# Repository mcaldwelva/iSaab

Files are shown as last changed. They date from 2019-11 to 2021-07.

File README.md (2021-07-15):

# iSaab
This module replaces the factory CD changer on the Saab 9-3 OG and 9-5 OG. All controls behave as the original, with the following exceptions:
* RDM does not change tracks when switching to shuffle mode

* In shuffle mode, the NXT and preset buttons are used to change the display text. NXT will rotate through the tags. Each preset button will select: 1) Track Title, 2) Album Title, 3) Album Artist, 4) Track Artist, 5) Genere, or 6) Year, respectively. Pressing the same preset again will return the display to normal.

* The 9-5 intro scan controls have been repurposed for pause and resume

## Parts

This is based on the [BlueSaab 3.5mm module](http://bluesaab.blogspot.com/2014/03/how-to-build-your-own-35mm-version-of.html) with some modifications to incorporate a sound card and reduce power consumption. The following or similar parts are required:

* [iSaab board](https://oshpark.com/shared_projects/o4QRu2nz)

* [ICs, caps, resistors, etc.](https://www.mouser.com/ProjectManager/ProjectDetail.aspx?AccessID=5A5DA965B5)

* [TE 827229-1 connector](https://www.connectorpeople.com/Connector/TYCO-AMP-TE_CONNECTIVITY/8/827229-1)

* [VS1053 breakout board](https://www.amazon.com/VS1053B-Arduino-Breakout-Real-time-Recording/dp/B07KNV2YTM)

* FTDI cable

* 9-5 only: CD Changer Connector Harness (400129243)

## Build

The BOM components are labeled to match the board. Cut the ribbon cable and strip the even wires (only the bottom row is used) so that they can be solderd in place with the MCU from the underside of the board.

| VS1053 Pin | AVR Pin | Ribbon Pin |
| ---:|:--- | --- |
| 5V | 20 | 1 |
| GND | 22 | 2 |
| CARDCS | 6 (D4)  | 3 |
| MISO | 18 | 4 |
| MOSI | 17 | 5 |
| SCK | 19 | 6 |
| XCS | 13 (D7) | 7 |
| XRESET | 15 (D9) | 8 |
| XDCS | 12 (D6) | 9 |
| DREQ | 5  (D3) | 10 |

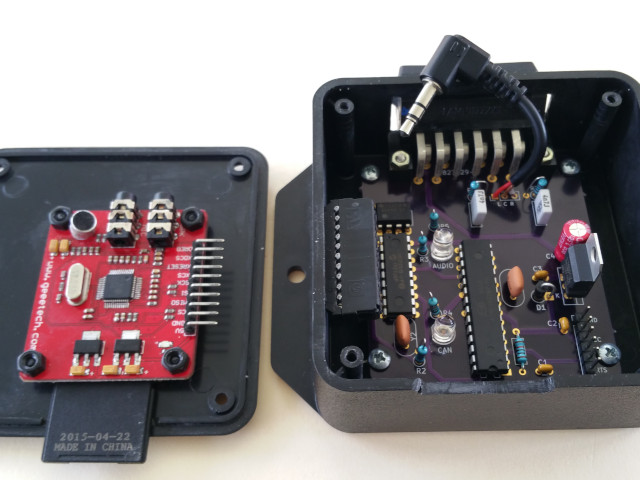
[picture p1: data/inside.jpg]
inside


## Software

* Use Arduino 1.8.12 (or higher)

* Apply the [SD library patch](https://raw.githubusercontent.com/mcaldwelva/iSaab/master/data/SD.diff) to fix issues with closing files, allow extended ASCII characters in file names, and exclude hidden/system files from directory listings:

> C:\Program Files (x86)\Arduino\libraries> patch -p1 < %HOMEPATH%\Documents\Arduino\iSaab\data\SD.diff

* Upload the iSaab code to the module using an FTDI cable

## Usage
* Format an SD card with FAT32. Third-party tools are needed to format SD cards larger than 32GB (e.g.
http://www.ridgecrop.demon.co.uk/index.htm?fat32format.htm)

* Place FLAC, Ogg Vorbis, MP3, AAC, or WMA music files into sub-directories, up-to three levels deep

* Files are played in filesystem order, which may not be as they appear in your OS. Third-party tools can be used to sort the filesystem to play in the desired order (e.g. http://www.anerty.net/software/file/DriveSort.php)

* Place [patch053.bin](https://raw.githubusercontent.com/mcaldwelva/iSaab/master/data/patch053.bin) in the root folder to enable FLAC playback.

* Create presets.txt in the root, containing up to 6 comma separated numbers. Each number represents the play-order of the file on the file system.

* Connect the module to the CD changer port in the trunk:
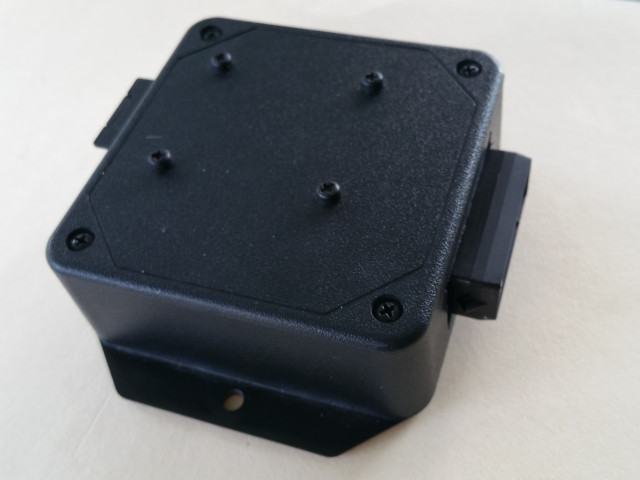
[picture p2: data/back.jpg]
back


## Troubleshooting
* The disc and track numbers are changing on the display but nothing is playing. This is expected behavior when seeking tracks. You may see this when the CD changer turns on, when selecting a preset, or between tracks in shuffle mode.

* If play doesn't start when the CD changer is selected, ensure the SD card is fully inserted. If the module is still unrespsonive, it may be necessary to disconnect and reconnect it for a hard boot.

* Only connect or disconnnect the module while the car is off and key removed from the ingition.

* When the module is shutdown, only the LED on the daughter card will remain lit to indicate power. The module draws ~13mA in this state.

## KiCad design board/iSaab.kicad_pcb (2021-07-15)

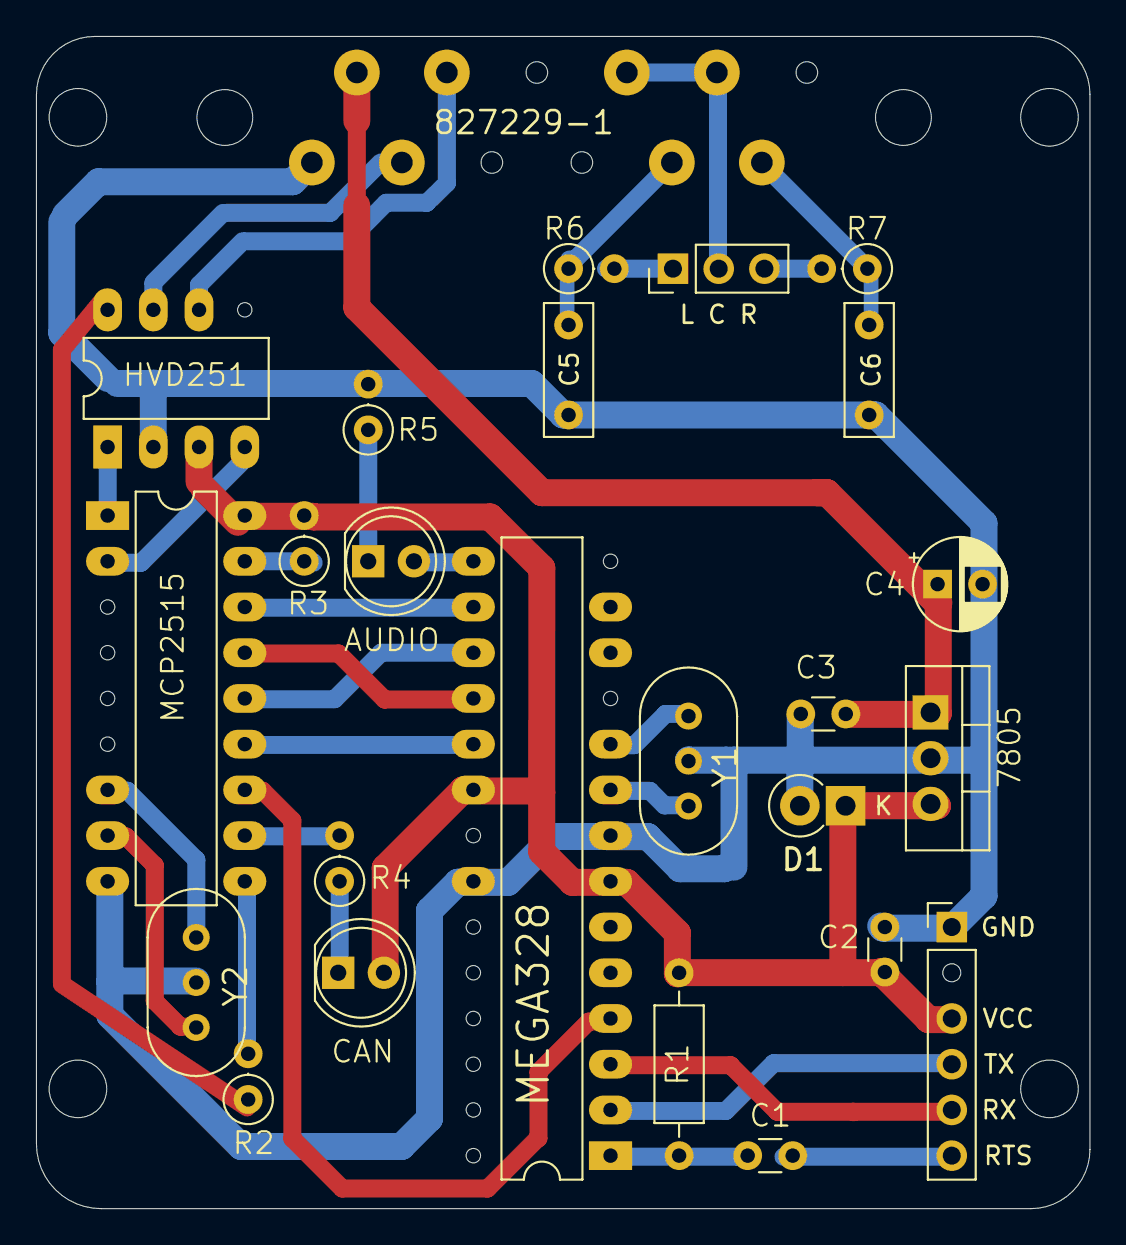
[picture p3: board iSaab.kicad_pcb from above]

Board: 2 copper layers, 58.5 x 65.1 mm, 29 parts (0 on the bottom side), 32 nets.

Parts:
@HOLE0, @HOLE1, @HOLE2, @HOLE3: (no value)
AUDIO: 5V; LED_D5.0mm
Audio In: L C R; PinHeader_1x03_P2.54mm_Vertical
C1, C2: 0.1uF; C_Disc_D3.0mm_W1.6mm_P2.50mm
C3: 470nF; C_Disc_D3.0mm_W1.6mm_P2.50mm
C4: 1uF; CP_Radial_D5.0mm_P2.50mm
C5, C6: 4.7nF; C_Rect_L7.2mm_W2.5mm_P5.00mm_FKS2_FKP2_MKS2_MKP2
CAN: 5V; LED_D5.0mm
D1: 1N4007-01; D_DO-41_SOD81_P2.54mm_Vertical_KathodeUp
IC1: MCP2515; DIP-18_W7.62mm_LongPads
IC2: HVD251; DIP-8_W7.62mm_LongPads
IC3: MEGA328; DIP-28_W7.62mm_LongPads
IC4: 7805; TO-220-3_Vertical
JP1: FTDI; PinHeader_1x06_P2.54mm_Vertical
R1: 10K; R_Axial_DIN0207_L6.3mm_D2.5mm_P10.16mm_Horizontal
R2, R3: 10K; R_Axial_DIN0207_L6.3mm_D2.5mm_P2.54mm_Vertical
R4, R5, R6, R7: 1K; R_Axial_DIN0207_L6.3mm_D2.5mm_P2.54mm_Vertical
U$5: 827229-1
Y1, Y2: 16MHz; Resonator-3Pin_W10.0mm_H5.0mm

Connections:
+5V: C2.1, CAN.2, D1.1, IC1.18, IC2.3, IC3.7, IC3.20, IC4.3, JP1.3, R1.1, R3.2
+12: C3.1, C4.1, IC4.1, U$5.6
CANH: IC2.7, U$5.11
CANL: IC2.6, U$5.5
CS: IC1.16, IC3.16
GBUF: Audio In.2, U$5.2, U$5.3
GND: C2.2, C3.2, C4.2, C5.1, C6.1, D1.2, IC1.9, IC2.2, IC3.8, IC3.22, IC4.2, JP1.1, R5.2, U$5.12, Y1.2, Y2.2
INT: IC1.12, IC3.4
LOUT: C5.2, R6.1, U$5.8
MISO: IC1.15, IC3.18
MOSI: IC1.14, IC3.17
unnamed: CAN.1, R4.1
unnamed: AUDIO.1, R5.1
unnamed: Audio In.1, R6.2
unnamed: Audio In.3, R7.2
unnamed: IC1.17, R3.1
OSC1: IC1.8, Y2.3
OSC2: IC1.7, Y2.1
RESET: C1.1, IC3.1, R1.2
ROUT: C6.2, R7.1, U$5.7
RTS: C1.2, JP1.6
RX: IC3.3, JP1.5
RX0BF: IC1.11, R4.2
RX1BF: IC1.10, R2.2
RXCAN: IC1.2, IC2.4
SCK: IC1.13, IC3.19
STDBY: IC2.8, R2.1
TOSC1: IC3.9, Y1.1
TOSC2: IC3.10, Y1.3
TX: IC3.2, JP1.4
TXCAN: IC1.1, IC2.1
XRESET: AUDIO.2, IC3.15

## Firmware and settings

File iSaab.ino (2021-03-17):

/*
 * iSaab -- A CD Changer replacement for Saab 9-3 OG and 9-5 OG
 *
 */

#include <SPI.h>
#include <avr/power.h>
#include <avr/sleep.h>
#include "CAN.h"
#include "CDC.h"
#include "iSaab.h"

uint8_t tag = AudioFile::NUM_TAGS;
bool newText;

// one-time setup
void setup() {
  // setup sound card
  CDC.setup();

#ifndef SERIALMODE
  // open I-Bus @ 47.619Kbps
  CAN.begin(47, high_filters, low_filters);

  // use IRQ for incoming messages
  SPI.usingInterrupt(MCP2515_INT);
  attachInterrupt(MCP2515_INT, processMessage, LOW);

  // reduce power
  set_sleep_mode(SLEEP_MODE_PWR_DOWN);
  power_usart0_disable();
  power_timer1_disable();
#else
  // open serial
  Serial.begin(115200);

  // use timer to read serial
  SPI.usingInterrupt(255);
  TCCR1A = 0;
  TCCR1B = _BV(WGM12) | _BV(CS12);
  OCR1A  = F_CPU / 256 / 2 - 1;
  TIMSK1 |= _BV(OCIE1A);

  // reduce power
  set_sleep_mode(SLEEP_MODE_IDLE);
#endif

  power_timer2_disable();
  power_adc_disable();
  power_twi_disable();
}


// main loop
void loop() {
  sleep_mode();
  CDC.loop();
}


// interrupt handler for incoming message
void processMessage() {
  static uint8_t gap = 0;

  // starting to receive CDC messages, wake up
  if (gap == 0) {
    CAN.setMode(CANClass::Normal);
  }

  // act on message
  CANClass::msg msg;
  if (receiveMessage(msg)) {
    switch (msg.id) {
      case RX_CDC_CONTROL:
        controlRequest(msg);
        gap = 15;
        break;

      case RX_CDC_POWER:
        powerRequest(msg);
        gap = 15;
        break;

      case RX_SID_REQUEST:
        displayRequest(msg); // comment out for vehicles equipped with Park Assist
        gap--;
        break;
    }
  }

  // no more CDC messages, go to sleep
  if (gap == 0) {
    CAN.setMode(CANClass::ListenOnly);
  }
}


void powerRequest(CANClass::msg &msg) {
  uint8_t action = msg.data[3] & 0x0f;

  // reply id
  msg.id = TX_CDC_POWER;

  // handle power request
  switch (action) {
    case 0x2: // active
      msg.data[3] = 0x16;
      break;
    case 0x3: // power on
      msg.data[3] = 0x03;
      CDC.on();
      break;
    case 0x8: // power off
      msg.data[3] = 0x19;
      CDC.off();
      break;
  }
  msg.data[0] = 0x32;
  msg.data[1] = 0x00;
  msg.data[2] = 0x00;
  msg.data[4] = 0x01;
  msg.data[5] = 0x02;
  msg.data[6] = 0x00;
  msg.data[7] = 0x00;
  sendMessage(msg);

  // send rest of sequence
  switch (action) {
    case 0x2: // active
      msg.data[3] = 0x36;
      break;
    case 0x3: // power on
      msg.data[3] = 0x22;
      break;
    case 0x8: // power off
      msg.data[3] = 0x38;
      break;
  }
  msg.data[4] = 0x00;
  msg.data[5] = 0x00;
  while (msg.data[0] < 0x62) {
    msg.data[0] += 0x10;
    sendMessage(msg);
  }
}


void controlRequest(CANClass::msg &msg) {
  static int8_t repeatCount;

  // reply id
  msg.id = TX_CDC_CONTROL;

  // ready, reply
  msg.data[0] = 0x60;

  // map CDC commands to methods
  repeatCount++;
  switch (msg.data[1]) {
    case 0x00: // no command
      msg.data[0] = 0x20;
      repeatCount = 0;
      CDC.normal();
      break;
    case 0x35: // TRACK >>
      CDC.skipTrack(repeatCount);
      break;
    case 0x36: // TRACK <<
      CDC.skipTrack(1 - repeatCount);
      break;
    case 0x45: // PLAY >>
      CDC.skipTime(repeatCount);
      break;
    case 0x46: // PLAY <<
      CDC.skipTime(-repeatCount);
      break;
    case 0x59: // NXT
      if (repeatCount == 1) {
        if (CDC.isShuffled()) {
          // rotate display tag
          tag = (tag + 1) % (AudioFile::NUM_TAGS + 1);
          newText = true;
        } else {
          CDC.nextDisc();
        }
      }
      break;
    case 0x68: // 1 - 6
      if (repeatCount == 1) {
        uint8_t preset = msg.data[2] - 1;
        if (CDC.isShuffled()) {
          // hide/show display tag
          tag = (preset == tag) ? AudioFile::NUM_TAGS : preset;
          newText = true;
        } else {
          CDC.preset(preset);
        }
      }
      break;
    case 0x76: // RDM toggle
      if (repeatCount == 1) {
        msg.data[0] |= 0x80;
        CDC.shuffle();
      }
      break;
    case 0xb0: // MUTE on
    case 0x14: // deselect CDC
    case 0x84: // SCAN disc
      CDC.pause();
      break;
    case 0xb1: // MUTE off
    case 0x24: // select CDC
    case 0x88: // SCAN magazine
      CDC.resume();
      break;
  }

  msg.data[1] = 0x00;

  // magazine
  msg.data[2] = 0b00111111;

  // play status, disc
  msg.data[3] = CDC.getState() & 0xf0;
  msg.data[3] |= CDC.getDisc() % 6 + 1;

  // track
  uint8_t track = CDC.getTrack() + 1;
  msg.data[4] = (track / 10) % 10;
  msg.data[4] <<= 4;
  msg.data[4] |= track % 10;

  // minutes
  uint16_t time = CDC.getTime();
  uint8_t min = time / 60;
  msg.data[5] = (min / 10) % 10;
  msg.data[5] <<= 4;
  msg.data[5] |= min % 10;

  // seconds
  uint8_t sec = time % 60;
  msg.data[6] = sec / 10;
  msg.data[6] <<= 4;
  msg.data[6] |= sec % 10;

  // married, RDM
  msg.data[7] = 0xd0;
  if (CDC.isShuffled()) msg.data[7] |= 0x20;

  // flag disc, track, or time change
  static uint8_t last[4] = {0x02, 0x01, 0x00, 0x00};
  if (memcmp(last, (msg.data + 3), sizeof(last))) {
    msg.data[0] |= 0x80;
    if (time == 0) newText = true;
    memcpy(last, (msg.data + 3), sizeof(last));
  }

  sendMessage(msg);
}


void displayRequest(CANClass::msg &msg) {
  // check row
  if (msg.data[0] == 0x00) {
    // check if display is wanted
    const String text = CDC.getText(tag);
    if (CDC.getState() == VS1053::Playing && text.length() > 0) {
      // check owner
      switch (msg.data[1]) {
        case 0x12: // iSaab
          // send text
          msg.id = TX_SID_TEXT;
          msg.data[1] = 0x96;

          for (int8_t id = 5, i = 0; id >= 0; id--) {
            // sequence id, start of sequence flag
            msg.data[0] = id;
            if (id == 5) msg.data[0] |= 0x40;

            // row id, new text flag
            msg.data[2] = (id < 3) ? 2 : 1;
            if (newText) msg.data[2] |= 0x80;

            // copy text
            switch (id) {
              default:
                msg.data[3] = text[i++];
                msg.data[4] = text[i++];
                msg.data[5] = text[i++];
                msg.data[6] = text[i++];
                msg.data[7] = text[i++];
                break;
              case 3:
                msg.data[3] = text[i++];
                msg.data[4] = text[i++];
                if (text[i] == ' ') i++;
                msg.data[5] = 0x00;
                msg.data[6] = 0x00;
                msg.data[7] = 0x00;
                break;
              case 0:
                msg.data[3] = text[i++];
                msg.data[4] = tag + 1;
                msg.data[5] = 0x00;
                msg.data[6] = 0x00;
                msg.data[7] = 0x00;
                break;
            }
            sendMessage(msg);
          }

          newText = false;
          msg.data[2] = 0x05; // keep
          break;
        case 0xff: // available
          newText = true;
          msg.data[2] = 0x03; // request
          break;
        default: // taken
          msg.data[2] = 0xff; // decline
          break;
      }
    } else {
      msg.data[2] = 0xff; // decline
    }

    // display request
    msg.id = TX_SID_REQUEST;
    msg.data[0] = 0x1f; // device
    msg.data[1] = 0x00; // row
    msg.data[3] = 0x12; // iSaab
    msg.data[4] = 0x00;
    msg.data[5] = 0x00;
    msg.data[6] = 0x00;
    msg.data[7] = 0x00;
    sendMessage(msg);
  }
}


void sendMessage(const CANClass::msg &msg) {
#ifndef SERIALMODE
  while (!CAN.send(msg));
#else
  Serial.print(msg.id, HEX);
  Serial.print(' ');

  for (uint8_t i = 0; i < 8; i++) {
    Serial.print(msg.data[i], HEX);
    Serial.print(' ');
  }

  Serial.println();
#endif
}


bool receiveMessage(CANClass::msg &msg) {
#ifndef SERIALMODE
  return CAN.receive(msg);
#else
  msg.id = RX_CDC_CONTROL;

  if (Serial.available()) {
    char c = Serial.read();

    switch (c) {
      case 'b':
        msg.id = RX_CDC_POWER;
        msg.data[3] = 0x03;
        break;
      case 'e':
        msg.id = RX_CDC_POWER;
        msg.data[3] = 0x08;
        break;
      case 't':
        msg.id = RX_SID_REQUEST;
        msg.data[0] = 0x00;
        msg.data[1] = 0x12;
        break;
      case 'p':
        msg.data[1] = 0xb0;
        break;
      case 'r':
        msg.data[1] = 0xb1;
        break;
      case '*':
        msg.data[1] = 0x76;
        break;
      case '>':
        msg.data[1] = 0x35;
        break;
      case '<':
        msg.data[1] = 0x36;
        break;
      case 'n':
        msg.data[1] = 0x59;
        break;
      case '-':
        msg.data[1] = 0x46;
        break;
      case '+':
        msg.data[1] = 0x45;
        break;
      case '1': case '2': case '3': case '4': case '5': case '6':
        msg.data[1] = 0x68;
        msg.data[2] = c - '0';
        break;
    }
  } else {
    msg.data[1] = 0x00;
  }

  return true;
#endif
}


#ifdef SERIALMODE
ISR(TIMER1_COMPA_vect) { processMessage(); }
#endif

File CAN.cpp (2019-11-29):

/*
 *  CAN implements CAN 2.0A (standard) interface for MCP2515 and related controllers
 *      based on work by Fabian Greif and Igor Real
 *   - Uses SPI transactions to allow bus sharing
 *   - Optionally use RX0BF or RX1BF to manage transceiver or mode indicator
 *
 */

#include <SPI.h>
#include <utility/Sd2PinMap.h>
#include "CAN.h"

#define MCP2515_SPI_SETTING SPISettings(10000000, MSBFIRST, SPI_MODE0)

CANClass CAN;

// setup pins, set CAN bus speed, optionally set filters, begin accepting messages
void CANClass::begin(uint16_t speed, const uint16_t high[] PROGMEM, const uint16_t low[] PROGMEM) {
  pinMode(MCP2515_CS, OUTPUT);
  digitalWrite(MCP2515_CS, HIGH);

  pinMode(MCP2515_IRQ, INPUT);

  SPI.begin();

  // reset MCP2515 to clear registers and put it into configuration mode
  SPI.beginTransaction(MCP2515_SPI_SETTING);
  fastDigitalWrite(MCP2515_CS, LOW);

  spiwrite(SPI_RESET);

  fastDigitalWrite(MCP2515_CS, HIGH);
  SPI.endTransaction();

  // wait for reset to complete
  delayMicroseconds(10);

  // configure bus speed
  uint8_t cnf1, cnf2, cnf3;
  switch (speed) {
    case 47:
      // http://www.microchip.com/forums/m/tm.aspx?m=236967&p=2
      cnf1 = 0xc7; cnf2 = 0xbe; cnf3 = 0x04;
      break;
    case 500:
      cnf1 = 0x01; cnf2 = 0x90; cnf3 = 0x02;
      break;
    case 250:
      cnf1 = 0x01; cnf2 = 0xB8; cnf3 = 0x05;
      break;
    case 125:
      cnf1 = 0x07; cnf2 = 0x90; cnf3 = 0x02;
      break;
    case 100:
      cnf1 = 0x03; cnf2 = 0xBA; cnf3 = 0x07;
      break;
    default:
      cnf1 = 0x00; cnf2 = 0x90; cnf3 = 0x02;
      break;
  }
  writeRegister(CNF1, cnf1);
  writeRegister(CNF2, cnf2);
  writeRegister(CNF3, cnf3);

  // always interrupt on high priority RX
  writeRegister(CANINTE, _BV(RX0IE));

  // allow rollover from RXB0 to RXB1
  modifyRegister(RXB0CTRL, _BV(BUKT), _BV(BUKT));

  // enable RXnBF registers for output
  writeRegister(BFPCTRL, _BV(B1BFE) | _BV(B0BFE));

  // configure filters
  setFilters(high, low);

  // leave config mode
  setMode(ListenOnly);
}


// transmit a message in FIFO order
// returns true if buffered successfully
bool CANClass::send(const msg &message) {
  static uint8_t id;
  uint8_t status = readStatus(SPI_READ_STATUS);

  // reset id if all buffers are clear
  if ((status & 0b01010100) == 0) {
    id = 14;
  }

  // calculate TX buffer address
  uint8_t address = (id & 0b11) << 1;

  // if that buffer isn't available we're done
  if (bit_is_set(status, address + 2)) {
    return false;
  }

  SPI.beginTransaction(MCP2515_SPI_SETTING);
  fastDigitalWrite(MCP2515_CS, LOW);

  // select buffer
  spiwrite(SPI_WRITE_TX | address);

  // standard id
  spiwrite(message.id >> 3);
  spiwrite(message.id << 5);

  // no extended id
  spiwrite(0x00);
  spiwrite(0x00);

  // DLC
  uint8_t length = message.header.length;
  if (message.header.rtr) {
    spiwrite(_BV(RTR) | length);
  } else {
    spiwrite(length);

    // data
    for (uint8_t t = 0; t < length; t++) {
      spiwrite(message.data[t]);
    }
  }

  fastDigitalWrite(MCP2515_CS, HIGH);
  SPI.endTransaction();

  // calculate the control register and priority
  uint8_t ctrlreg = (address << 3) + TXB0CTRL;
  uint8_t priority = id >> 2;

  // flag the buffer for transmission
  modifyRegister(ctrlreg, _BV(TXREQ) | _BV(TXP1) | _BV(TXP0), _BV(TXREQ) | priority);

  // decrement id, skipping invalid addresses
  id -= (id % 4) ? 1 : 2;

  return true;
}


// read the highest priority message available and clear its buffer
// returns true if a message was received
bool CANClass::receive(msg &message) {
  uint8_t address;
  uint8_t status = readStatus(SPI_RX_STATUS);

  // buffer 0 has the higher priority
  if (bit_is_set(status, 6)) {
    // message in buffer 0
    address = 0x00;
  } else if (bit_is_set(status, 7)) {
    // message in buffer 1
    address = 0x04;
  } else {
    // no message available
    return false;
  }

  SPI.beginTransaction(MCP2515_SPI_SETTING);
  fastDigitalWrite(MCP2515_CS, LOW);

  spiwrite(SPI_READ_RX | address);

  // standard id
  uint8_t sidh = spiread();
  uint8_t sidl = spiread();
  message.id = (sidh << 3) | (sidl >> 5);

  // skip extended id
  spiread();
  spiread();

  // DLC
  uint8_t length = spiread() & 0x0f;
  message.header.length = length;
  message.header.rtr = bit_is_set(sidl, SRR);

  // data
  if (!message.header.rtr) {
    for (uint8_t t = 0; t < length; t++) {
      message.data[t] = spiread();
    }
  }

  fastDigitalWrite(MCP2515_CS, HIGH);
  SPI.endTransaction();

  return true;
}


// change the operating mode of the can chip
void CANClass::setMode(Mode mode) {
  switch (mode) {
    case Normal:
      // transceiver on
      modifyRegister(BFPCTRL, _BV(B1BFS) | _BV(B0BFS), 0x00);

      // enable low priority RX and disable wake interrupts
      modifyRegister(CANINTE, _BV(WAKIE) | _BV(RX1IE), _BV(RX1IE));
      modifyRegister(CANINTF, _BV(WAKIF), 0x00);
      break;

    case ListenOnly:
      // disable low priority RX interrupt
      modifyRegister(CANINTE, _BV(RX1IE), 0x00);
      break;

    case Sleep:
      // enable wake interrupt
      modifyRegister(CANINTE, _BV(WAKIE), _BV(WAKIE));
      break;
  }

  // set controller mode
  modifyRegister(CANCTRL, _BV(REQOP2) | _BV(REQOP1) | _BV(REQOP0), mode);

  // wait until controller mode has been changed
  while ((readRegister(CANSTAT) & (_BV(REQOP2) | _BV(REQOP1) | _BV(REQOP0))) != mode);

  if (mode != Normal) {
    // transceiver standby
    modifyRegister(BFPCTRL, _BV(B1BFS) | _BV(B0BFS), _BV(B1BFS) | _BV(B0BFS));
  }
}
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

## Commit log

2016-03-08 fixed message transmission order
    [CAN.cpp]
2016-03-31 don't hog SPI
2016-04-02 allow changing SD card, full-speed SPI, extended ASCII filenames
2016-05-25 fixes potential issues on shutdown and changing tracks
    [VS1053.cpp]
2016-06-15 better fix for delayed shutdown
    [VS1053.cpp]
2016-08-21 improved track skipping in-folder
    [VS1053.h]
2016-08-30 always use the same power status
2016-10-12 fixed occasional dropped messages
    [CAN.cpp]
2017-03-08 no previous track in shuffle mode
2017-10-06 2 cancels is more reliable/less noise
    [VS1053.cpp]
2018-04-06 removed line drivers
2018-04-12 added output resistors
2018-05-19 minimize data interrupts
2018-08-23 not supporting ancient Arduino libraries
2018-08-28 safe update of current track number
2019-02-12 fixed byterate for DSD
    [VS1053.cpp]
2019-03-06 SD isn't thread-safe
2019-03-07 startup based on selected device
2019-12-04 add board
    [iSaab.kicad_pcb]
2020-01-21 net clean-up
    [iSaab.kicad_pcb]
2020-01-23 BOM update
2020-02-07 show resonator labels
    [iSaab.kicad_pcb]
2020-03-18 new board
2021-03-17 fix for empty folders
    [VS1053.h, iSaab.ino]
2021-07-15 fix skipped track when paused
    [iSaab.kicad_pcb]
